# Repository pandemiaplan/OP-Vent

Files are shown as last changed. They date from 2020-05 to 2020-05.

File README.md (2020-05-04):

# OP-Vent
A Simple, Open-Source Ventilator using a Proportional Solenoid Valve

Information gathered from https://op-vent.stanford.edu/ check it out!
Article about information at https://www.engadget.com/nvidia-open-source-ventilator-design-165732445.html

- [Code](/code)
- [PCB Design](/OPVentPCB_V2.2)
- [Documentation](https://op-vent.stanford.edu/docs/need.html)
- [Open-Source Pneumatics](https://op-vent.stanford.edu/open-source_pneumatics.html) / [CAD Model](/models/op-vent_open-source-components.STEP)
- [Off-the-Shelf Pneumatics](https://op-vent.stanford.edu/off-the-shelf_pneumatics.html) / [CAD Model](/models/op-vent_off-the-shelf-components.STEP)

## Video Introduction

OP-Vent Video Introduction (https://youtu.be/vAR43ow1w0Q)

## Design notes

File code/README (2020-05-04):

Open Source Proportional Solenoid Valve Ventilator

This directory contains code for an open-source proportional solenoid
valve ventilator.

Copyright 2020 Bill Dally
 
Licensed under the Ventilator Open Source License (the "License");
you may not use this file except in compliance with the License.
You may obtain a copy of the License at

./LICENSE

Unless required by applicable law or agreed to in writing, software
distributed under the License is distributed on an "AS IS" BASIS,
WITHOUT WARRANTIES OR CONDITIONS OF ANY KIND, either express or implied.
See the License for the specific language governing permissions and
limitations under the License.

Files in this directory are:

Makefile   Builds an executable using "make" and the AVR Crosspack Tools

Main Program Logic:
main.h	     Global variables and constant definitions
main.c	     Code for initialization and real-time clock callback
control.c    Control code for regulating flow, pressure, and volume
control.h    Defines for control.c
alarm.c	     Code relating to alarms
alarm.h	     Defines for alarm.c
ui.c	     The user interface - LCD and encoder, serial line, and test
ui.h	     Defines for ui.c
flow.c	     Code for dealing with flows
flow.h	     Defines for flow.c

Sensor Drivers:
honeywell_flow.c  Code to interface to the Honeywell Zephyr I2C airflow sensor
honeywell_flow.h  Defines for above
siargo.c     Code to interface ot the Siargo FS4800 via its analog output
siargo.h     Defines for above
nxp_pressure.c	  Code to interface to NXP MP3V5010 or MP3V5004 pressure sensors
nxp_pressure.h    Defines for above

Peripheral Drivers:
lcd.c	     Code to manage the LCD display
lcd.h	     Defines for above
pwm.c	     Code to generate a pulse-width modulated signal to drive the solenoid valve
pwm.h	     Defines for above
serial.c     Serial interface
serial.h     Defines for above
timer.c	     Code to generate the real-time clock interrupt and schedule routines on this clock
timer.h	     Defines for above
two_wire.c   Codes for the Two-Wire (I2C) interface
two_wire.h   Defines for above

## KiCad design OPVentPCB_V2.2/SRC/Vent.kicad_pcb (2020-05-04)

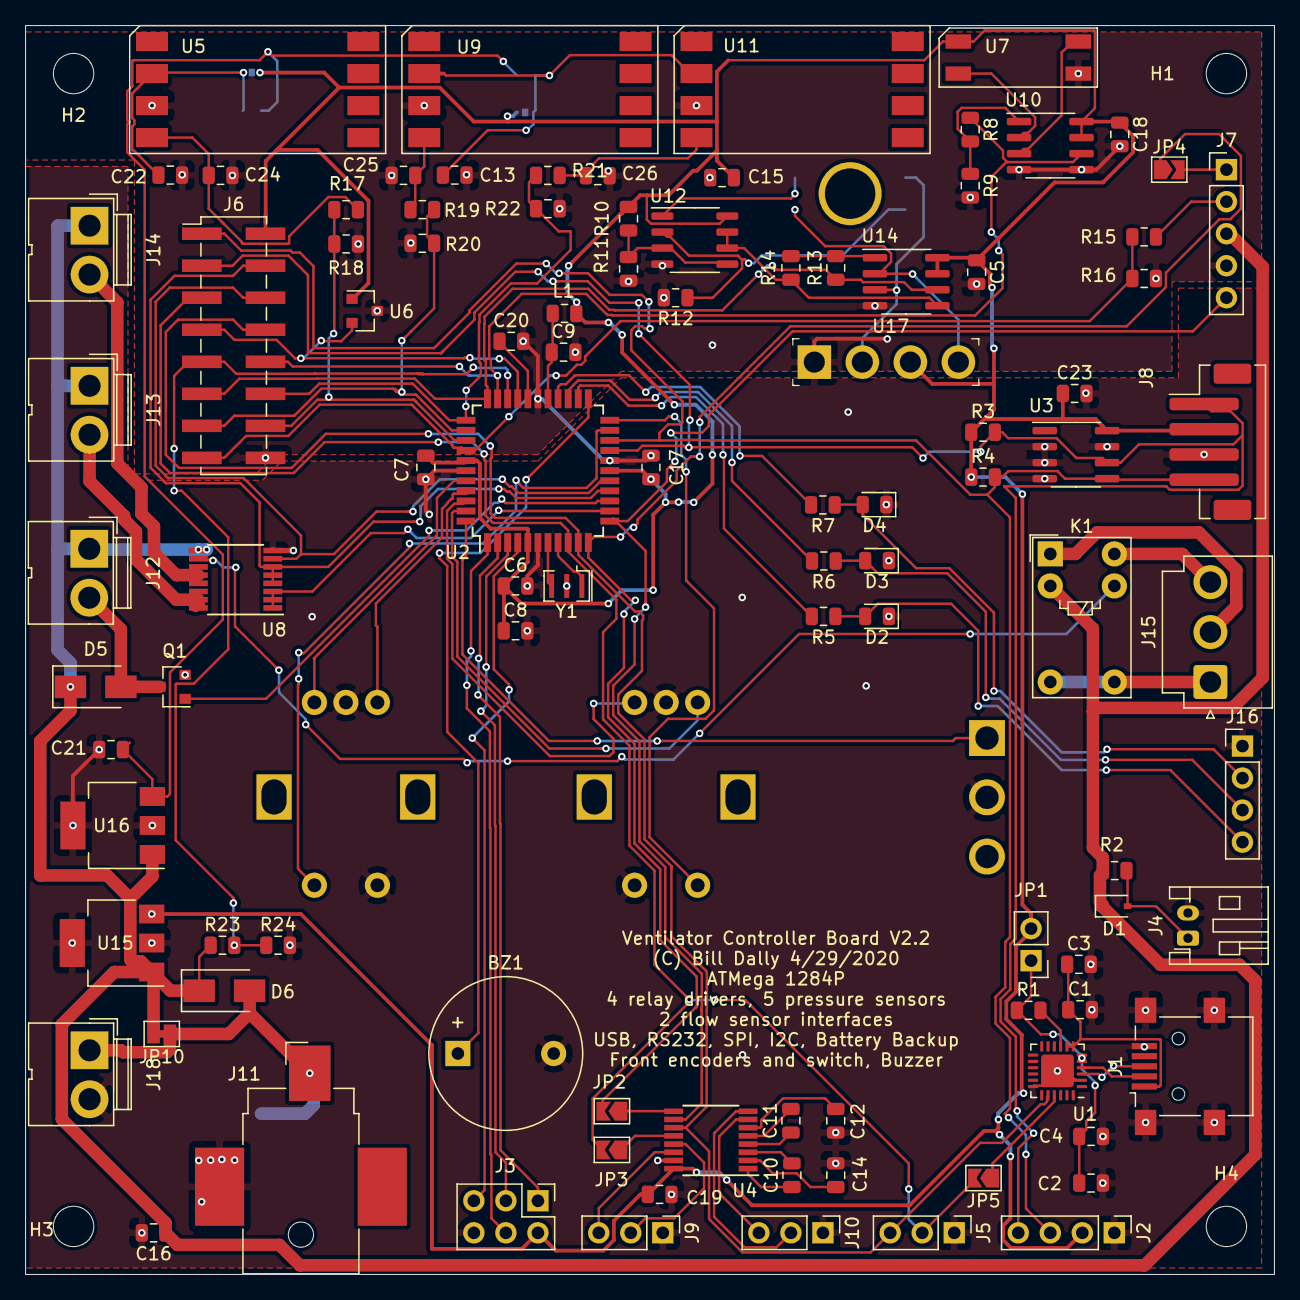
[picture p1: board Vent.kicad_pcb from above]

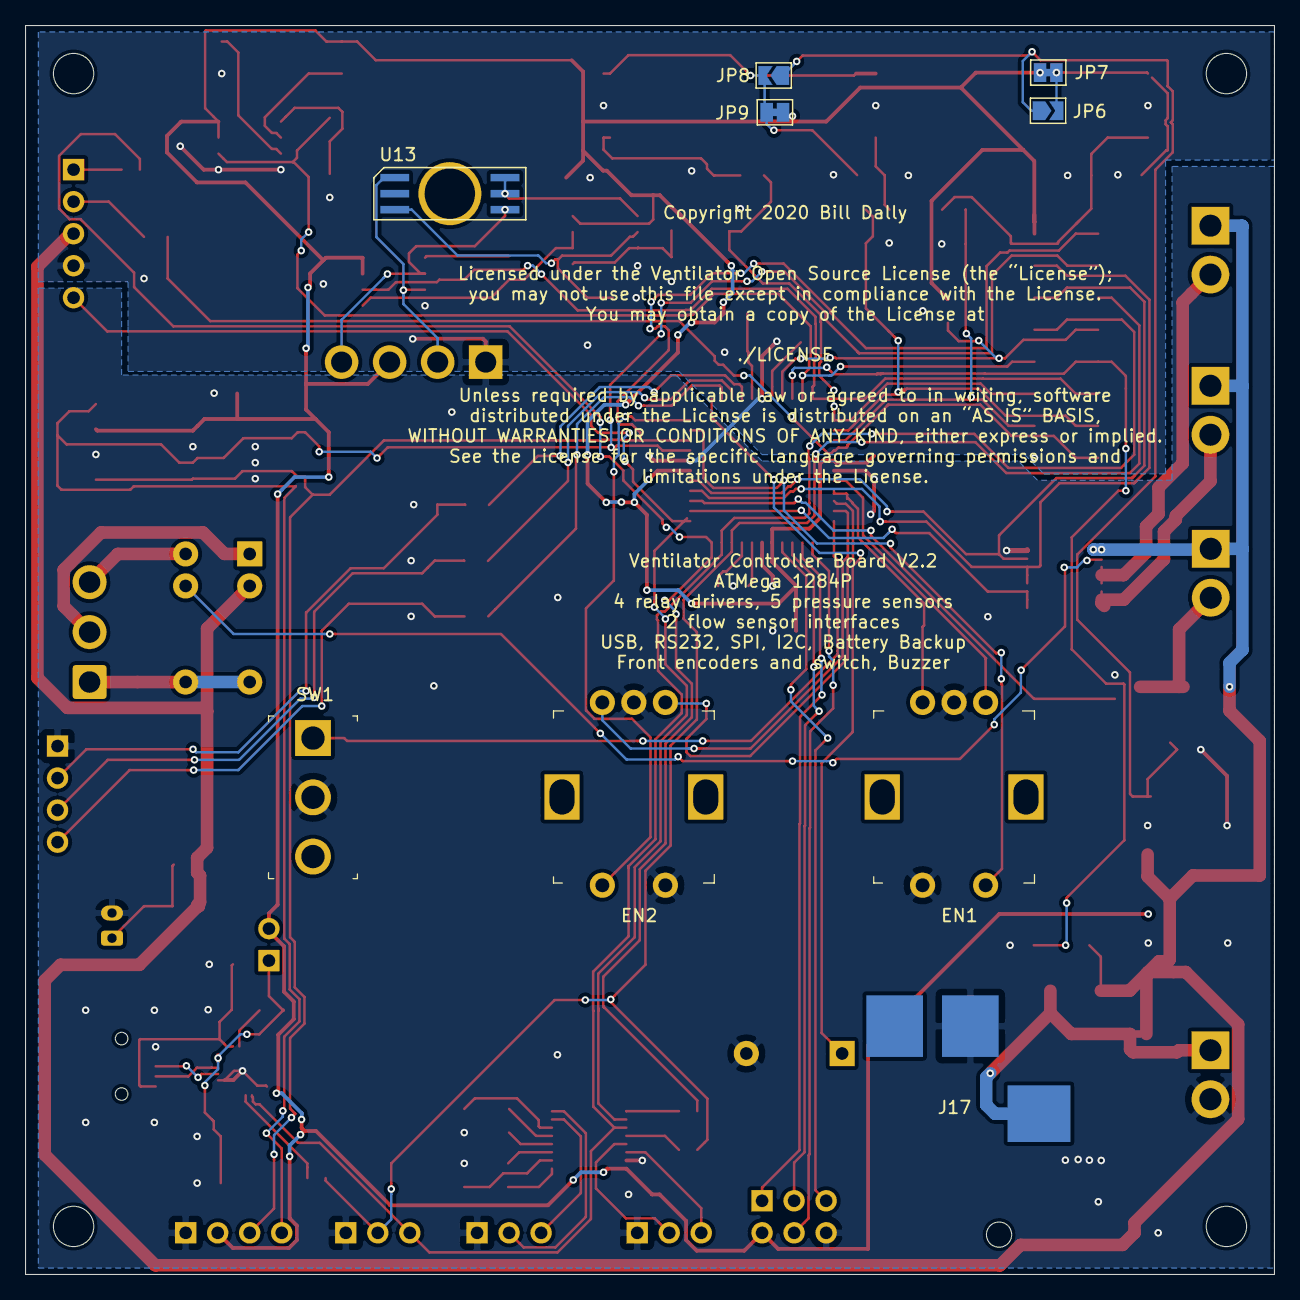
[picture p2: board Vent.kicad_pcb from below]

Board: 2 copper layers, 99.1 x 99.1 mm, 113 parts (9 on the bottom side), 88 nets.

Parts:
BZ1: CMI-1295IC-0385T; Buzzer_12x9.5RM7.6
C1, C2: 4.7uF; C_0805_2012Metric
C3, C4, C5, C6, C10, C11, C12, C13, C14, C15, C17, C18, C19, C20, C21, C22, C23: 100nF; C_0805_2012Metric
C7, C16: 10uF; C_0805_2012Metric
C8, C9: 1uF; C_0805_2012Metric
C24, C25, C26: 470pF; C_0805_2012Metric
D1: D_Schottky; D_SOD-323
D2, D3, D4: LED; D_0805_2012Metric
D5, D6: ES1D; D_SMA
EN1: Func_Sel; Rotary_Encoder_Switched_EN11
EN2: Parm_Sel; Rotary_Encoder_Switched_EN11
H1, H2, H3, H4: MountingHole; MountingHole_3.2mm_M3
J1: USB_B_Mini; USB_Mini-B_Lumberg_2486_01_Horizontal
J2: I2C; PinHeader_1x04_P2.54mm_Vertical
J3: Program; PinHeader_2x03_P2.54mm_Vertical
J4: Batt; JST_PH_S2B-PH-K_1x02_P2.00mm_Horizontal
J5: Serial 3.3V; PinHeader_1x03_P2.54mm_Vertical
J6: Test & Spare; PinHeader_2x08_P2.54mm_Vertical_SMD
J7: Siargo; PinHeader_1x05_P2.54mm_Vertical
J8: Honeywell; JST_PH_B4B-PH-SM4-TB_1x04-1MP_P2.00mm_Vertical
J9: RS232; PinHeader_1x03_P2.54mm_Vertical
J10: RS232B; PinHeader_1x03_P2.54mm_Vertical
J11: P12V_Horiz_Front; BarrelJack_CUI_PJ-036AH-SMT_Horizontal
J12: Sol1; JWT_A3963_1x02_P3.96mm_Vertical
J13: Sol2; JWT_A3963_1x02_P3.96mm_Vertical
J14: Sol3; JWT_A3963_1x02_P3.96mm_Vertical
J15: Relay; JST_VH_B3P-VH_1x03_P3.96mm_Vertical
J16: LEDs; PinHeader_1x04_P2.54mm_Vertical
J17: P12V_Vert_Back; BarrelJack_CUI_PJ006A
J18: P12V; JWT_A3963_1x02_P3.96mm_Vertical
JP1: USB Power Jumper; PinHeader_1x02_P2.54mm_Vertical
JP2: RS232B; SolderJumper-2_P1.3mm_Open_TrianglePad1.0x1.5mm
JP3: RS232; SolderJumper-2_P1.3mm_Open_TrianglePad1.0x1.5mm
JP4: Siargo Serial; SolderJumper-2_P1.3mm_Open_TrianglePad1.0x1.5mm
JP5: USB; SolderJumper-2_P1.3mm_Open_TrianglePad1.0x1.5mm
JP6: LP1_5V; SolderJumper-2_P1.3mm_Open_TrianglePad1.0x1.5mm
JP7: LP1_3P3V; SolderJumper-2_P1.3mm_Bridged_Pad1.0x1.5mm
JP8: LP2_5V; SolderJumper-2_P1.3mm_Open_TrianglePad1.0x1.5mm
JP9: LP2_3P3V; SolderJumper-2_P1.3mm_Bridged_Pad1.0x1.5mm
JP10: Power; SolderJumper-2_P1.3mm_Bridged_Pad1.0x1.5mm
K1: G5V-1; Relay_SPDT_Omron_G5V-1
L1: 10uH; L_0805_2012Metric
Q1: PMV20XNE; SOT-23
R1, R3, R4: 2.2K; R_0805_2012Metric
R2, R5, R6, R7: 330; R_0805_2012Metric
R8, R13: 220k; R_0805_2012Metric
R9, R12, R14, R18, R20, R22: 10k; R_0805_2012Metric
R10: 330k; R_0805_2012Metric
R11: 100k; R_0805_2012Metric
R15: 35.7k 0.1%; R_0805_2012Metric
R16: 10k 0.1%; R_0805_2012Metric
R17, R19, R21: 5.1k; R_0805_2012Metric
R23: 26.4K 1%; R_0805_2012Metric
R24: 10k 1%; R_0805_2012Metric
SW1: SW_SPDT; Toggle_Switch_100SP1T1B4M2QE
U1: CP2102N-A01-GQFN24; QFN-24-1EP_4x4mm_P0.5mm_EP2.6x2.6mm
U2: ATmega1284P-AU; TQFP-44_10x10mm_P0.8mm
U3: MC24CM02; SOIC-8_3.9x4.9mm_P1.27mm
U4: MAX3232; TSSOP-16_4.4x5mm_P0.65mm
U5, U11: MP3V5010GP; NXP_Pressure_Sensor
U6: MCP9700AT-ETT; SOT-23
U7: NBPMANN150PGUNV; Honeywell_NBP
U8: ULN2003; TSSOP-16_4.4x5mm_P0.65mm
U9: MPXV5010GP; NXP_Pressure_Sensor
U10, U14: MCP6N11; SOIC-8_3.9x4.9mm_P1.27mm
U12: LMV358; SO-8_3.9x4.9mm_P1.27mm
U13: 2SMPP-03; 2SMPP
U15: 78M33; SOT-223-3_TabPin2
U16: 78L05; SOT-223-3_TabPin2
U17: MX10GP; SIP-4_W3.81mm
Y1: Resonator; Resonator_SMD_muRata_CSTxExxV-3Pin_3.0x1.1mm

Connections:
/A6: J6.9, R23.2, R24.1, U2.31
/A7: J6.7, U2.30, U6.2
/ALARM: BZ1.1, U2.23
/AREF: C20.1, U2.29
/AVCC: C9.1, L1.2, U2.27
/ENC11: EN1.A, U2.40
/ENC12: EN1.B, U2.41
/ENC21: EN2.A, U2.42
/ENC22: EN2.B, U2.43
/FLOW: J6.15, R15.2, R16.1, U2.37
/HP: J6.10, R8.1, U2.32, U10.6
/L1: D2.2, J16.4, R5.1
/L2: D3.2, J16.3, R6.1
/L3: D4.2, J16.2, R7.1
/LED1: R5.2, U2.24
/LED2: R6.2, U2.25
/LED3: R7.2, U2.26
/LP1: J6.14, R17.2, R18.1, U2.36
/LP2: J6.13, R19.2, R20.1, U2.35
/LP3: J6.12, R21.2, R22.1, U2.34
/LP4: J6.11, R13.1, U2.33, U14.6
/MISO: J3.1, U2.2
/MOSI: J3.4, U2.1
/OC1A: Q1.1, U2.14
/OC1B: U2.13, U8.1, U8.2, U8.3
/PD6: J6.4, U2.15, U8.4, U8.5, U8.6
/PD7: J6.6, U2.16, U8.7
/Pressure_Sensors/DLB: R12.1, U12.2, U13.3
/Pressure_Sensors/DLP+: U13.1, U14.3, U17.2
/Pressure_Sensors/DLP-: U13.4, U14.2, U17.4
/Pressure_Sensors/DLPM: R13.2, R14.1, U14.1
/Pressure_Sensors/DLPREF: R14.2, U12.6, U12.7, U14.5
/Pressure_Sensors/DLT: U12.1, U13.5, U13.6
/Pressure_Sensors/HP+: U7.4, U10.3
/Pressure_Sensors/HP-: U7.2, U10.2
/Pressure_Sensors/HPM: R8.2, R9.1, U10.1
/Pressure_Sensors/LP1R: C24.1, R17.1, U5.4
/Pressure_Sensors/LP2R: C25.1, R19.1, U9.4
/Pressure_Sensors/LP3R: C26.1, R21.1, U11.4
/Pressure_Sensors/V1V: R10.2, R11.1, U12.3, U12.5
/Pressure_Sensors/VP1: C22.1, JP6.2, JP7.2, U5.2
/Pressure_Sensors/VP2: C13.1, JP8.2, JP9.2, U9.2, U11.2
/RELAY_C: J15.1, K1.5, K1.6
/RELAY_NC: J15.2, K1.1
/RELAY_NO: J15.3, K1.10
/RESETN: J3.5, U2.4
/RS232/C1+: C10.1, U4.1
/RS232/C1-: C10.2, U4.3
/RS232/C2+: C11.1, U4.4
/RS232/C2-: C11.2, U4.5
/RS232/RR1: J9.2, U4.13
/RS232/RR2: J10.2, U4.8
/RS232/RT1: J9.3, U4.14
/RS232/RT2: J10.3, U4.7
/RS232/VS+: C14.1, U4.2
/RS232/VS-: C12.1, U4.6
/RXD: J5.2, J6.5, JP3.2, JP5.2, U2.9
/RXD1: JP2.2, JP4.1, U2.11
/SCL: J2.4, J6.3, J8.1, R3.2, U2.19, U3.6
/SCLK: J3.3, U2.3
/SDA: J2.3, J6.1, J8.4, R4.2, U2.20, U3.5
/SFLOW: J7.2, R15.1
/SOL1: D5.2, J12.2, Q1.3
/SOL2: J13.2, U8.14, U8.15, U8.16
/SOL3: J14.2, U8.11, U8.12, U8.13
/SOL4: K1.9, U8.10
/SRXD: JP3.1, U4.12
/SRXD1: JP2.1, U4.9
/STX: J7.1, JP4.2
/SW1: SW1.1, U2.44
/SW2: EN1.S1, U2.21
/SW3: EN2.S2, U2.22
/TXD: J5.3, J6.8, U1.20, U2.10, U4.11
/TXD1: J7.5, U2.12, U4.10
/URXD: JP5.1, U1.21
/USB_Serial/D+: J1.3, U1.3
/USB_Serial/D-: J1.2, U1.4
/USB_Serial/URST_N: R1.2, U1.9
/USB_Serial/USB_VCC: C2.1, C4.1, JP1.1, R1.1, U1.5, U1.6
/USB_Serial/VBUS: C1.1, C3.1, J1.1, U1.7, U1.8
/V5: C21.1, JP6.1, JP8.1, U16.3
/V12: C16.1, D1.1, D5.1, D6.1, J7.3, J12.1, J13.1, J14.1, JP10.2, K1.2, R2.2, R23.1, U8.9, U15.1, U16.1
/V12A: D6.2, J11.1, J17.1, J18.1, JP10.1
/XTAL1: U2.8, Y1.1
/XTAL2: U2.7, Y1.3
GND: BZ1.2, C1.2, C2.2, C3.2, C4.2, C5.2, C6.2, C7.2, C8.2, C9.2, C12.2, C13.2, C14.2, C15.2, C16.2, C17.2, C18.2, C19.2, C20.2, C21.2, C22.2, C23.2, C24.2, C25.2, C26.2, D2.1, D3.1, D4.1, EN1.C, EN1.S2, EN2.C, EN2.S1, J1.5, J1.6, J2.1, J3.6, J4.2, J5.1, J6.16, J7.4, J8.3, J9.1, J10.1, J11.2, J16.1, J17.2, J18.2, Q1.2, R9.2, R11.2, R12.2, R16.2, R18.2, R20.2, R22.2, R24.2, SW1.2, U1.2, U1.18, U1.25, U2.6, U2.18, U2.28, U2.39, U3.2, U3.3, U3.4, U3.7, U4.15, U5.3, U6.3, U7.3, U8.8, U9.3, U10.4, U10.5, U11.3, U12.4, U14.4, U15.2, U16.2, U17.1, Y1.2
unnamed: D1.2, J4.1, R2.1
VCC: C5.1, C6.1, C7.1, C8.1, C15.1, C17.1, C18.1, C19.1, C23.1, J2.2, J3.2, J6.2, J8.2, JP1.2, JP7.1, JP9.1, L1.1, R3.1, R4.1, R10.1, U2.5, U2.17, U2.38, U3.8, U4.16, U6.1, U7.1, U10.7, U10.8, U12.8, U14.7, U14.8, U15.3, U17.3

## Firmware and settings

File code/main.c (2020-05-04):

// Name: main.c
// RTC call back and variable initialization for open source proportional solenoid valve ventilator
//
// Copyright 2020 Bill Dally
//
// Licensed under the Ventilator Open Source License (the "License");
// you may not use this file except in compliance with the License.
// You may obtain a copy of the License at
// 
// ./LICENSE
// 
// Unless required by applicable law or agreed to in writing, software
// distributed under the License is distributed on an "AS IS" BASIS,
// WITHOUT WARRANTIES OR CONDITIONS OF ANY KIND, either express or implied.
// See the License for the specific language governing permissions and
// limitations under the License.
//  

/* 
 * Simple Proportional Valve Ventilator
 *
 * Global Variables
 * Input
 *   bpm - beats per minute 8-40
 *   etoix10 - etoi ratio times 10 - 10 to 40
 *   vol - tidal volume in ml
 *   maxp - maximum pressure
 *   p_trig_on - patient triggering enabled
 *   trigp - patient triggering pressure
 *   min_minute_vol - alarm threshold
 * 
 * Derived
 *   tcy - cycle time in ms - 60000/bpm
 *   ton - on time in ms - tcy * 1/(1 + etoi)
 *   flow - vol (ml) / ton (s) - in ml/s
 *
 * Fixed
 *   trise - rise time in ms
 *   tfall - fall time in ms
 *
 * State
 *   time - time within current cycle in ms
 *
 * Function driven by 1ms RTC 
 *   increment time - wrap at tcy
 *   if time < ton
 *     get current flow - start A/D or read I2C
 *     run control law - driven from A/D interrupt
 *     read pressure and log it
 *
 * UI functions
 *  b - set bpm
 *  e - set etoi x 10
 *  v - set tidal volume
 *  c - run calibration - sweep valve and measure flow
 *  ? - menu
 *     
 * Later - add patient intiated breath
 * Later - ramp flow up and down
 *
 */

#include <avr/io.h>
#include <util/delay.h>
#include "adc.h"
#include "serial.h"
#include "timer.h"
#include "pwm.h"
#include "main.h"
#include "flow.h"
#include "siargo.h"
#include "ui.h"
#include "two_wire.h"
#include "nxp_pressure.h"
#include "lcd.h"
#include "control.h"
#include "alarm.h"

volatile static timer_id_t atimer ;

void init_parameters(void) {
  set_defaults() ; // includes gains
  cflow = 0 ;
  time = 0 ;
  ltime = 0 ;
  log_step = 1 ;
  run = 0 ;
  front_panel_lock = 0 ;
  b_hist_ptr = 0 ;
  alarm = 0 ; // no alarms set
  ftest = 0 ;
}

void init_ports(void)
{
  DDRD = 1<<OC1A_PD | 1<<OC1B_PD | 1<<7 ; // PWM out on 4 and 5, pin 7 for timing monitor
  DDRC = 1<<LED1_PC | 1<<LED2_PC | 1<<LED3_PC | 1<<ALARM_PC ;
  PORTC = (1<<SW2_C) | (1<<SW3_C) ; // pullups
  PORTB = (1<<SW1_B) | (1<<ENC11_B) | (1<<ENC12_B) | (1<<ENC21_B) | (1<<ENC22_B) ; // for pullups
}

void set_leds(uint8_t val) { // bottom 3 bits to LEDs
  PORTD = (PORTD & 0xC7) | ((val & 0x7) <<3) ;
}

// Check for pressure drop at patient
uint8_t patient_trigger() {
  if((p_trig_on == 1) && (mpressure < (peep - trigp))) {
    trig_time += TICK ;
    if(trig_time >= TRIG_TIME) return(1) ;
  }
  else {
    trig_time = 0 ;
  }
  return(0) ; 
}


// Call every TICK ms
void callback(void) {
  PORTD |= 0x80 ; // pulse PD7 for debug
  update_encoders() ; // check encoders and update settings
  time = time + TICK ;
  if(time >= tcy) {
    time = 0 ;
    once = 0 ; // end of breath event hasn't happend once yet
    pip = 0 ; // reset each breath
  }
  if(run == 1) {
    //if(time == 0) set_leds(6) ;
    //if(time == ton) set_leds(2) ;
    mflow = get_flow() ;
    mpressure = nxp_get_pressure() ; //** general pressure sensor later
    smpressure = (mpressure + smpressure*PS_CONST) >> PS_SHIFT ; // smooth pressure
    if(smpressure > alarm_pip) alarm_trig(ALARM_MAXP) ;
    if(smpressure > pip) pip = smpressure ; // record max inpiritory pressure
    if(time == 0) peep = smpressure ; // record peep pressure
    mvol = mvol + mflow ; // ** if no flow sensor, use cflow
    
    if((time >= tarm) && patient_trigger()) time=0 ;  // patient initiated breathing
    /*
    if((time < ton) && ((time & 0x3F) == 0)) {
      //uint16_t dmvol = (mvol >> 9) ;
      //put_word(dmvol) ; space() ; put_word(mpressure) ; crlf() ;
      put_word(mflow) ; space() ;
      }*/

    control() ; // sets cflow

    if((time > ton + TGAP) && (once == 0)) { // after end of breath - run once
      once = 1 ;
      bvol = (mvol * MVOL_VOLx256k)>>18 ;
      bpip = pip ;
      if(run ==1) {
	put_word(bvol) ; space() ;
	put_word(bpip) ; space() ;
	put_word(minute_vol) ; space() ;
	put_word(toff) ; crlf() ;}
      check_alarms() ;
    }

    set_flow(cflow) ;
    if((log_on == 1) && (log_ptr < MAX_LOG)) {
      if(ltime == 0) {
	flog[log_ptr][0] = mflow ;
	flog[log_ptr][1] = mpressure ;
	flog[log_ptr][2] = cflow ;
	flog[log_ptr][3] = error ;
	flog[log_ptr][4] = i_err ;
	flog[log_ptr][5] = d_err ;
	flog[log_ptr][6] = press_err ;
	flog[log_ptr][7] = press_derr ; 
	flog[log_ptr][8] = ferr ;
	flog[log_ptr][9] = frac ;
	flog[log_ptr][10] = mode ;
	log_ptr++ ; // dot() ;
      }
      ltime++ ;
      if(ltime >= log_step) ltime = 0 ;
    }
  } else {
    if(ftest == 1) { // flow test using control
      mflow = get_flow() ;
      cflow = pid_ff(flow, mflow) ;
      set_flow(cflow) ;
    }
  }

  // variables to update on 256ms interval - to keep LCD from blurring
  if((time & 0xFF) == 0) {
    xtime = time ;
    xsmpress = smpressure ;
    xmflow = mflow ;
  }
  // could check run 0 here
  PORTD &= 0x7F ;  // D7 back down - for debug
}

int main(void)
{
  init_parameters() ;
  init_ports() ;
  adc_init() ;
  serial_init() ;
  set_leds(1) ;
  timer_init() ;
  set_leds(2) ;
  pwm_init() ;
  set_leds(3) ;
  tw_init() ;
  set_leds(4) ;
  siargo_init() ; // if using siargo sensor
  nxp_init(); // if using NXP sensor
  set_leds(5) ;
  lcd_init() ;
  lcd_clear() ;  
  set_leds(6) ;
  compute_derived() ;
  print_values() ;
  set_leds(6) ;
  read_f2p_tab() ; // read table from EE PROM
  set_leds(7) ;
  atimer = timer_start(TICK, callback, PERIODIC); // call sample_callback every TICK ms

  put_string_P(PSTR("PSV Vent:\n\r")) ;
  while(1) {
    ui() ;
  }

  return 0;   /* never reached */
}

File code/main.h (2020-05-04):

// main.h
// global include file for open-source proportional solenoid valve ventilator
//
// Copyright 2020 Bill Dally
// 
// Licensed under the Ventilator Open Source License (the "License");
// you may not use this file except in compliance with the License.
// You may obtain a copy of the License at
// 
// ./LICENSE
// 
// Unless required by applicable law or agreed to in writing, software
// distributed under the License is distributed on an "AS IS" BASIS,
// WITHOUT WARRANTIES OR CONDITIONS OF ANY KIND, either express or implied.
// See the License for the specific language governing permissions and
// limitations under the License.
//


#include <avr/io.h>
#include <util/delay.h>
#include "params.h"

// default parameter values
#define DEF_BPM 15
#define DEF_VOL 400
#define DEF_ETOI 20
#define DEF_MAXP 600 // mm H2O
#define DEF_TRIGP 25 // mm H2O - negative offset from PEEP
#define TRIG_TIME 50 // 50ms

// valve specific PWM parameters
#define MIN_PWM 600          // point at which flow starts
#define MAX_PWM 1200         // 
#define MAX_FLOW_MLPS 1167   // in mL/sec
#define MAX_FLOW_MLPM 70000  // in mL/min
#define SENSOR_MAX_FLOW 1667 // ml/sec - for 100 L/m sensors

#define TICK 1 // ms per RTC invocation

#define MAX_LOG 256 // for logging
#define MAX_LOG_CHAN 11 //

// Control
// 48 4 8 / 16 worked on one unit
// 0 1 0 / 16 (or 0 2 0 / 32) is super reliable
#define PGAIN 0  // 
#define IGAIN 2
#define DGAIN 0  // 
#define PRESS_GAIN 100 
#define PRESS_DGAIN 10 
#define PRESS_IGAIN 2 // multiplicative with igain 
#define GAIN_DIV_LG2 5 // gains are in 1/16s
#define GAIN_DIVISOR (1<<GAIN_DIV_LG2)

// guard band of 32mm H2O to switch from flow to pressure regulation
#define PGUARD_LG2 5                      //
#define PGUARD (1<<PGUARD_LG2)            // guard band on pressure regulation - must be a power of 2
#define HALF_PGUARD (1<<(PGUARD_LG2-1))   // 

// Times
#define TIME_FF 120 // time for feed forward before engaging PID
#define TGAP 200 // time from end of ton to doing end of breath activities
#define TOFFSET 60 // turn on delay - turn off delay - in ms
#define TMAX_MUL 1.3 // maximum extension to make volume


// to smooth pressure with IIR filter
// smooth = (new + smooth * (2^n-1)) * 2^-n
#define PS_SHIFT 3
#define PS_CONST ((1<<PS_SHIFT)-1)

// to limit windup
#define MAX_IERR 4000
#define MIN_IERR -4000

#define TRISE 20 // ms
#define TPULSE 3 // ms - time to pulse valve at full PWM to break stickiness

// I/O Definitions
// LEDs are on Port B
#define LED1_PC 5 
#define LED2_PC 6 
#define LED3_PC 7
#define ALARM_PC 4

// PWM on Port D
#define OC1A_PD 5
#define OC1B_PD 4

// Encoders on Port B
#define ENC11_B 0
#define ENC12_B 1
#define ENC21_B 2
#define ENC22_B 3

#define SW1_B 4 // switch is  PD2
#define SW2_C 2 // encoder switches
#define SW3_C 3

// EE PROM Locations
#define EER_SIARGO_ZERO 2 // 1 word
#define EER_NXP_ZERO 4 // 1 word
#define EER_F2P 128 // F2P_SZ * 2 locations

// derived values
volatile uint16_t tcy ;         // cycle time ms
volatile uint16_t ton ;         // inhale time ms
volatile uint16_t toff ;        // time when volume completed
volatile uint16_t tarm ;        // point at which patient can initiate
volatile uint16_t tdown ;       // time to start ramp down
volatile uint16_t trise ;      // rise time
volatile uint16_t tmax ;        // maximum extension to make TV
volatile int16_t flow ;        // flow during inhale in mlps 0-833 at 50L/min
volatile uint16_t flow_mlpm ;   // flow during inhale in mlpm 0-50000 at 50L/min
volatile int16_t flow_step ;   // step of flow during rise - per TICK
volatile int16_t tflow ;   // target flow
volatile int32_t vol_limit ;   // tidal volume limit - multiplied by integration factor 1000/TICK

// control values
volatile int16_t cflow ;       // commanded flow
volatile int16_t mflow ;       // measured flow
volatile int16_t error ;       // error - signed value
volatile int16_t d_err ;       // derivative of error - delta since last TICK
volatile int16_t i_err ;       // integral of error
volatile int16_t oerror ;      // one back for derivative
volatile int16_t o2error ;     // two back to smooth derivative

// pressures
volatile int16_t mpressure ;   // measured pressure mm H2O - signed
volatile int16_t smpressure ;  // smoothed measured pressure - avoids ringing on transitoins - can be 200mm
volatile int16_t peep ;        // peep pressure - recorded before start of breath
volatile int16_t pip ;         // maximum inspiratory pressure this breath - running maximum
volatile int16_t bpip ;        // maximum inspiratory pressure for last breath - set at end of breath
volatile int16_t press_err ;   // pressure error
volatile int16_t opress_err ;  // old pressure error
volatile int16_t press_derr ;   // diff pressure error
volatile int16_t ferr ;        // attenuated error in guard-band 
volatile int16_t frac ;        // fraction attenuated
volatile int16_t mode ;        // how gain is calculated
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

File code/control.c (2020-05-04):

// control.c
// control routines for open-source proportional solenoid valve ventilator
// (c) Bill Dally, April 2020
//
// Copyright 2020 Bill Dally
// 
// Licensed under the Ventilator Open Source License (the "License");
// you may not use this file except in compliance with the License.
// You may obtain a copy of the License at
// 
// ./LICENSE
// 
// Unless required by applicable law or agreed to in writing, software
// distributed under the License is distributed on an "AS IS" BASIS,
// WITHOUT WARRANTIES OR CONDITIONS OF ANY KIND, either express or implied.
// See the License for the specific language governing permissions and
// limitations under the License.
//

#include "main.h"

uint8_t first ;

// proportional and derivative errors
void compute_flow_errors(void) {
  o2error = oerror ;
  oerror = error ; // for diff
  error = flow - mflow ; // error signal
  // smooth d_err - two step
  d_err = (error - oerror) + (error - o2error) ;
}

void limit_i_err(void) {
  if(i_err > MAX_IERR) i_err = MAX_IERR ;
  if(i_err < MIN_IERR) i_err = MIN_IERR ;
}

//PID control law with feed forward
int16_t pid_ff(uint16_t flow, uint16_t mflow) {
  compute_flow_errors() ;
  i_err = i_err + error ;
  limit_i_err() ;
  int32_t lcflow = (int32_t) flow + (((int32_t)error*pgain + (int32_t) i_err * igain + (int32_t) d_err*dgain) >> GAIN_DIV_LG2) ;
  cflow = lcflow ;
  if(cflow < 0) cflow = 0 ;
  if(cflow > MAX_FLOW_MLPS) cflow = MAX_FLOW_MLPS ;
  //put_word(flow); comma() ; put_word(mflow) ; comma() ;
  //put_signed(error) ; comma() ; put_signed(cflow); crlf() ;
  return(cflow) ;
}

//PID control law with feed forward and one-sided pressure
int16_t pid_ff_press(uint16_t flow, uint16_t mflow, uint16_t maxp, uint16_t mpressure) {
  int32_t lcflow ; // temp
  // old computation
  compute_flow_errors() ;
  // pressure error
  opress_err = press_err ; // for derivative
  press_err = maxp - mpressure ; //
  press_derr = press_err - opress_err ;
  lcflow = (int32_t) flow + (((int32_t)error*pgain + (int32_t) d_err*dgain) >> GAIN_DIV_LG2 ) ;
  if(mpressure <= (maxp - PGUARD)) { // regulate flow - ** add derivative of pressure to look ahead
    mode = 0 ;
    i_err = i_err + error ;// identical to above
    limit_i_err() ;
    lcflow += ((int32_t) i_err * igain) >> GAIN_DIV_LG2 ; 
  } else if((mpressure > (maxp - PGUARD)) && (mpressure < maxp)) { // guard band - ramp down flow integral error
    mode = 1 ;
    frac = (maxp - mpressure) - HALF_PGUARD ; // numerator - denom is PGUARD - zero in last half of guard band
    if(frac < 0) frac = 0 ;
    int32_t lferr = ((int32_t) error * frac) >> PGUARD_LG2 ;  // scale by frac/PGUARD
    ferr = lferr ;
    i_err = i_err + ferr ;
    limit_i_err() ;
    lcflow += ((int32_t) i_err * igain) >> GAIN_DIV_LG2 ; 
  }else { // regulate pressure
    mode = 2 ;
    i_err = i_err + (press_err * press_igain) ; // integrate pressure error - with press_igain.  Use regular igain below.
    limit_i_err() ;
    lcflow += ((int32_t)press_err * press_gain + (int32_t) i_err * igain + (int32_t) press_derr * press_dgain) >> GAIN_DIV_LG2 ;
  }
  cflow = lcflow ;
  //int32_t p_cont = (press_err * press_gain + press_derr * press_dgain) >> GAIN_DIV_LG2  ;
  //  if(p_cont > 0) p_cont = 0 ; // one sided 
  //cflow = cflow + p_cont ;
  
  if(cflow < 0) cflow = 0 ;
  if(cflow > MAX_FLOW_MLPS) cflow = MAX_FLOW_MLPS ;
  //put_word(flow); comma() ; put_word(mflow) ; comma() ;
  //put_signed(error) ; comma() ; put_signed(cflow); crlf() ;
  return(cflow) ;
}

// vestigial routine - no longer used
void volume_control(void) {
  if(time == 0) { // first cycle, just feed forward
    tflow = flow_step ;
    i_err = 0 ; // zero integral error
    mvol = 0 ; // zero measured volume each breath
    cflow = pid_ff(tflow, mflow) ;
  } else if(time < trise) {
    i_err = 0 ; // avoid windup during transient
    tflow = tflow + flow_step ;
    cflow = pid_ff(tflow, mflow) ;
    tdown = time ; // for next segment
  } else if(mvol <= (vol_limit - ramp_vol)) {
    tflow = flow ;
    cflow = pid_ff(tflow, mflow) ;
    tdown = time ; // for next segment
  } else { // within ramp of target volume
    i_err = 0 ; // or perhaps reduce gain
    uint16_t tleft = trise - (time - tdown) ; // time left in ramp
    uint32_t rramp_vol = (tflow * tleft)/ (2 * TICK) ; // remaining ramp volume
    if(mvol >= (vol_limit - rramp_vol)) tflow = tflow - flow_step ;
    if (mvol >= vol_limit) tflow = 0 ; // cut to zero if at target volume
    cflow = pid_ff(tflow, mflow) ;
    if(tflow <= 0 ) {
      tflow = 0 ;
      cflow = 0 ;
    } else {
      cflow = pid_ff(tflow, mflow) ;
    }
  }
  if(time > (ton + trise*4)) cflow = 0 ;
}

// simple time based control
void control(void) {
  if(time == 0) {
    mvol = 0 ; // zero measured volume at start of each breath
    first = 1 ;  // to capture first cycle at end of vol
    tflow = flow_step ;
  }
  /* pulse didn't help much - disabling it
  if((time > 0) && (time <= TPULSE)) { // pulse valve at start of cycle
    if(smpressure <= maxp) cflow = MAX_FLOW_MLPS ;
    else cflow = 0 ;
    i_err = 0 ;
    } else */
  if(time < trise) { // rise time is open-loop ramp - bang-bang pressure
    if(smpressure <= maxp) cflow = tflow ;
    else cflow = 0 ;
    tflow = tflow + flow_step ;
    i_err = 0 ;
  } else if(time < TIME_FF) { // first cycles, just feed forward
    cflow = pid_ff_press(flow, mflow, maxp, mpressure) ; // to prime d_err
    if(smpressure < maxp) cflow = flow ;
    else cflow = 0 ; // bang-bang pressure regulation during open-loop period
    i_err = 0 ; // zero integral error
  } else if(time < ton) { // PID control for remainder of breath
    cflow = pid_ff_press(flow, mflow, maxp, mpressure) ;
  } else if(mvol < vol_limit) { // wait for volume
    if(time < tmax) cflow = pid_ff_press(flow, mflow, maxp, mpressure) ;
    else cflow = 0 ;
  } else {
    if(first == 1) {
      toff = time ;
      first = 0 ;
    }
    cflow = 0 ;
  }
}
